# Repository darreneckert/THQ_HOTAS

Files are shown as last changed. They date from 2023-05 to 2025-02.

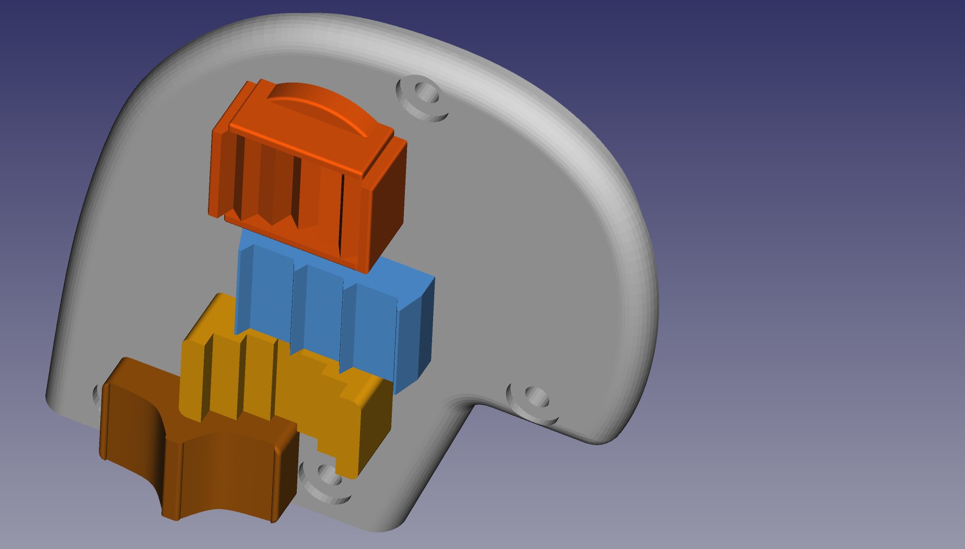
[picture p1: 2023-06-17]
Docs/Proposed Right Throttle Switches and Hat Layout.jpeg

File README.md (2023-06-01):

# THQ_HOTAS
My attempt to add additional controls to the VKB Throttle Quadrant module (THQ).

I plan to use one or two Arduino Pro Micro boards to add a mini joystick, various buttons, hats and switches to the VKB THQ using Marco_596178's Printables throttle bodies (https://www.printables.com/model/405514-vkb-thq-hotas-throttle) and Huzarski's hat switches (https://www.thingiverse.com/thing:3641494)

This is my first time using an Arduino and working on a DIY Hotas.

This repository will contain the Arduino code, schematics and documentation for this project.

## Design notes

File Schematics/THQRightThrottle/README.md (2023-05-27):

# THQRightThrottle

## Description

This is a [LibrePCB](https://librepcb.org) project!

My attempt to add additional controls to VKB THQ using @Marco_596178's Printables throttle grips

## License

This work is licensed under the Creative Commons Attribution-NonCommercial 4.0 International License. To view a copy of this license, visit http://creativecommons.org/licenses/by-nc/4.0/ or send a letter to Creative Commons, PO Box 1866, Mountain View, CA 94042, USA.

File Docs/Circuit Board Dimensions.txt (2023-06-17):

Circuit Board Dimensions (approx.)

Main Board
Length = 43mm
Width  = 33mm

5_Way Hat Board
Length = 23mm
Width  = 20mm

Switches Board
Length = 26mm
Width  = 25mm

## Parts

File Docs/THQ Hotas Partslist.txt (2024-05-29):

THQ Hotas Partslist

THQ Throttle bodies - https://www.printables.com/model/405514-vkb-thq-hotas-throttle

Hat Switches (2x 2-Way, 1x 3-Way, 1x 5-Way) - https://www.thingiverse.com/thing:3641494

12x 0.7mm SPST Micro Tactile Switch - https://www.jaycar.com.au/0-7mm-spst-micro-tactile-switch/p/SP0600

Warthog slew sensor upgrade module, requires 3.3V so need 3.3V/8MHz version of Pro Micro - https://www.aliexpress.com/item/1005002554918990.html?spm=a2g0o.order_list.order_list_main.10.64db1802wJn1Tb

3.3V Arduino Pro Micro - https://www.aliexpress.com/item/1348800135.html?spm=a2g0o.order_list.order_list_main.21.64db1802wJn1Tb

Prototype boards manufactured thru PCBWay/JLCPCB, designed using EasyEDA

Various wires and connectors

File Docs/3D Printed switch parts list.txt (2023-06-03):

2/3/4/5-Way Switches from https://www.thingiverse.com/thing:3641494

2-Way switch parts (Speedbrake)
	2x Alps SKHHAQA010
	1x Cap #A
	1x Stem #A
	1x Body #A
	1x Hat Cap SB
	
2-Way switch parts (Comms)
	2x Alps SKHHAQA010
	1x Cap #A
	1x Stem #A
	1x Body #A
	1x Hat Cap Comms
	
3-Way switch parts (Misc)
	3x Alps SKHHAQA010
	1x Cap #A
	1x Stem #A
	1x Body #A
	1x Bottom #A
	1x Hat Cap Boat

5-Way switch parts
	5x Alps SKHHAQA010
	1x Cap #D
	1x Stem #C
	1x Body #D
	1x Bottom #A
	1x Hat Cap Stadium

Totals
	12x Alps SKHHAQA010
	3x  Cap #A
	1x  Cap #D
	3x  Stem #A
	1x  Stem #C
	3x  Body #A/#B
	1x  Body #D
	2x  Bottom #A
	1x  Hat Cap SB
	1x  Hat Cap Comms
	1x  Hat Cap Boat
	1x  Hat Cap Stadium

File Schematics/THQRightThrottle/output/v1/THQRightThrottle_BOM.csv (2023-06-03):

Quantity | Designators | Value | Device | Package
2 | J_2WAY1, J_2WAY2 |  | Generic Pin Socket 2.54mm 1x03 ⌀1.0mm | Pin Socket 2.54mm 1x03 ⌀1.0mm
1 | J_3WAY |  | Generic Pin Socket 2.54mm 1x04 ⌀1.0mm | Pin Socket 2.54mm 1x04 ⌀1.0mm
5 | J_DOWN, J_LEFT, J_PUSH, J_RIGHT, J_UP |  | Generic Pin Header 2.54mm 1x02 ⌀1.0mm | Pin Header 2.54mm 1x02 ⌀1.0mm
2 | J_HAT, J_HAT2 |  | Generic Pin Header 2.54mm 1x06 ⌀1.0mm | Pin Header 2.54mm 1x06 ⌀1.0mm
2 | J_SWITCHES, J_SWITCHES2 |  | Generic Pin Header 2.54mm 1x08 ⌀1.0mm | Pin Header 2.54mm 1x08 ⌀1.0mm
1 | J_TDC |  | Generic Pin Header 2.54mm 1x05 ⌀1.0mm | Pin Header 2.54mm 1x05 ⌀1.0mm
1 | U_PRO_MICRO |  | Pro Micro - Micro USB | Pro Micro - Micro USB

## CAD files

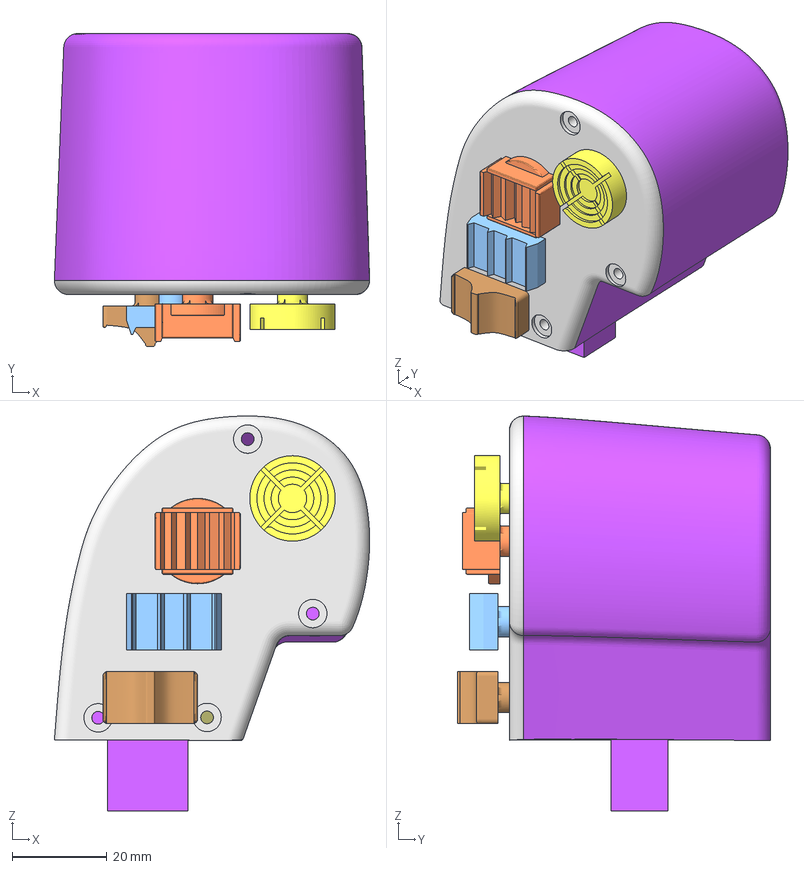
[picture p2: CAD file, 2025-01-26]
Docs/Right THrottle Switches and Hat Layout.FCStd
66.5 x 66.0 x 83.3 mm
Main Board
VKB THQ Hotas v1 - RH Side Panel
Speedbrake
Comms_HAT
Boat
VKB THQ Hotas v1 - RH Body
Stadium_HAT

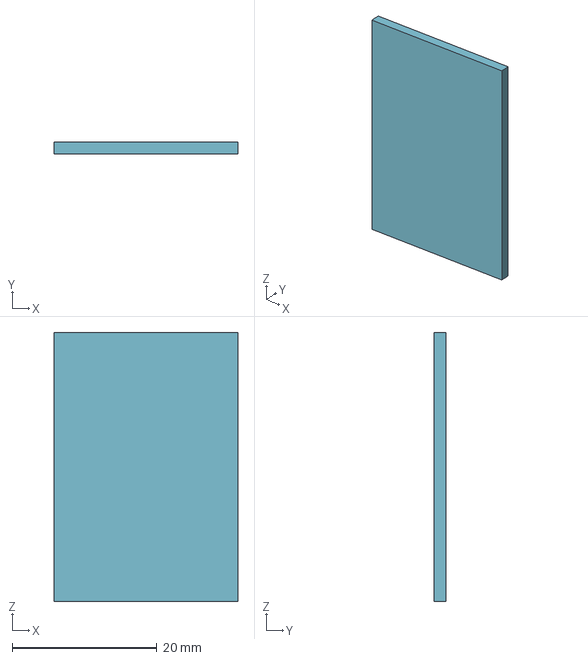
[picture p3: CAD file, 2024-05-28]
Docs/Right Throttle Board.FCStd
25.4 x 1.60 x 37.2 mm

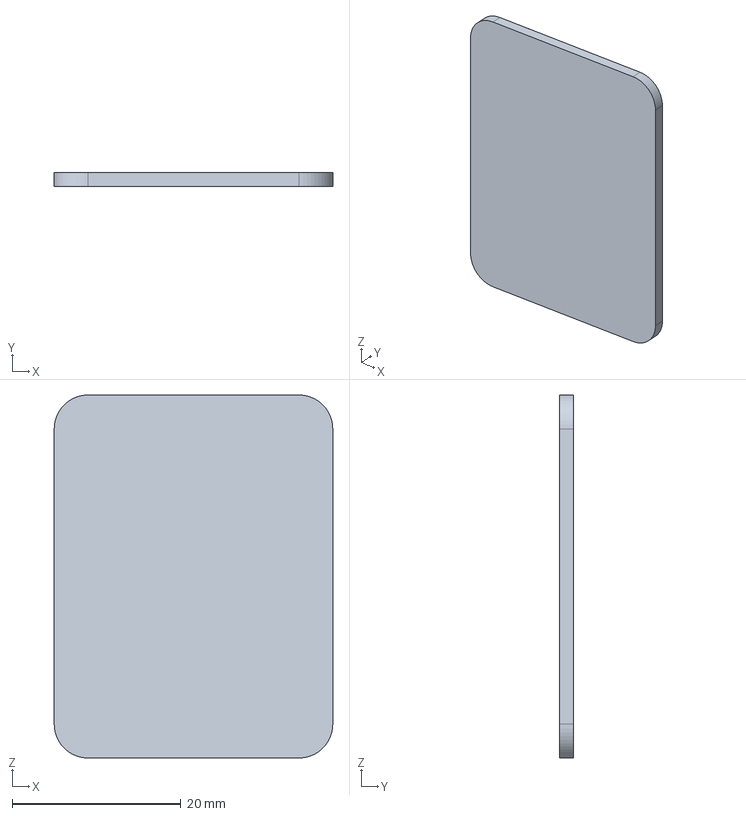
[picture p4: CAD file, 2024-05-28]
Docs/Right Throttle Board rev1.FCStd
33.0 x 1.60 x 43.0 mm

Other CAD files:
Docs/Right Throttle Board.stl

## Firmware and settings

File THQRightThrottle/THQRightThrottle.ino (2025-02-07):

// Program to setup an Arduino Pro Micro to provide additional 
// controls (ministick, hats, buttons and switches) to a
// VKB Throttle Quadrant (THQ) module, making use of the 3D
// printed left and right throttle bodies that have been designed 
// by Marco (@Marco_596178) at Printerbale.com which can be found 
// here - https://www.printables.com/model/405514-vkb-thq-hotas-throttle
//
// This sketch is for the right throttle controls 
//
// Darren Eckert
// 2023-06-12
// Version 0.2

#include <Joystick.h>
#define DEBUGTHQ TRUE


const int HID_ID = 0x26;              // Unique HID Device ID for this arduino
const int uBtns  = 9;                 // Number of buttons on the device
const int hBtns  = 4;                 // Hat switches Up, Right, Down, Left
const int tDelay = 50;                // Time delay for loop() in ms, may need adjusting
int i;                                // Generic counter

// Define digital pin to be used for each  button
int sHat[hBtns] = {0, 1, 4, 2};       // 5-Way Hat U/R/D/L
int sBtn[uBtns] = {3,                 // 5-Way Hat Push switch,   HID button 0
                   6, 7,              // 2-Way Speedbrake switch, HID buttons 1 and 2
                   8, 9,              // 2-Way Comms switch,      HID buttons 3 and 4
                   10, 14, 16,         // 3-Way Misc switch,      HID buttons 5, 6 and 7
                   15};                // TDC Push switch         HID button 8


// Define Analog pins for each axis
const int xTDC_Axis  = A3;            // Analog pin for TDC X-Axis
const int yTDC_Axis  = A2;            // Analog pin for TDC Y-Axis
  

// Default states for axes and buttons
int xTDC = 0;
int yTDC = 0;

bool hVal_Changed = false;
int sBtn_CurrState, hBtn_CurrState;
int sBtn_LastState[uBtns] = {0, 0, 0, 0, 0, 0, 0, 0, 0};
int hBtn_LastState[hBtns] = {0, 0, 0, 0};


// Joystick (HID ID, Type, Buttons, Hats, X-Aix, Y-Axis, Z-Axis, Rx-Axis, Ry-Axis, Rz-Axis, Rudder, Throttle, Accelerator, Brake, Steering);
Joystick_ THQ(HID_ID, JOYSTICK_TYPE_JOYSTICK, uBtns, 1, true, true, false, false, false, false, false, false, false, false, false);
const bool initAutoSendState = true;


void setup() {
  pinMode(xTDC_Axis, INPUT);
  pinMode(yTDC_Axis, INPUT);

  // Initialise digital pin modes and enable pull-up resistors
  for (i=0; i<uBtns-1; i++) {
    pinMode(sBtn[i], INPUT);
    digitalWrite (sBtn[i], HIGH);
  }
  digitalWrite (sBtn[8], LOW);     // TDC Push needs to be reversed else it reads as pushed when not

  for (i=0; i<hBtns; i++) {
    pinMode(sHat[i], INPUT);
    digitalWrite (sHat[i], HIGH);
  }

  THQ.begin(initAutoSendState);

  #ifdef DEBUGTHQ
    Serial.begin(9600);
  #endif
}

void loop() {
  // Read axes and send to HID
  // X-Axis
  xTDC = analogRead(xTDC_Axis);
  //Serial.print("X Axis = ");
  //Serial.print(xTDC);
  xTDC = map(xTDC, 0, 1023, 0, 255);   // scale resolution to reduce jittering, need to test if necessary
  //Serial.print(", mapping to ");
  //Serial.println(xTDC);
  THQ.setXAxis(xTDC);

  // Y-Axis
  yTDC = analogRead(yTDC_Axis);
  //Serial.print(", Y Axis = ");
  //Serial.println(yTDC);
  yTDC = map(yTDC, 0, 1023, 0, 255);  // scale resolution to reduce jittering, need to test if necessary
  //Serial.print(", mapping to ");
  //Serial.println(yTDC);
  THQ.setYAxis(yTDC);

  // Check for change in state of each hat direction and if it has changed send new state to HID
  for (i=0; i<hBtns; i++)  {
    hBtn_CurrState = !digitalRead(sHat[i]);
   // Serial.print("Current state of sHat[");
   // Serial.print(i);
   // Serial.print("] = ");
   // Serial.println(hBtn_CurrState);
    if (hBtn_CurrState != hBtn_LastState[i]) {
      hVal_Changed = true;
      //Serial.println("State changed from last check");
      hBtn_LastState[i] = hBtn_CurrState;
    }
  }

  // Something has changed since last check
  if (hVal_Changed) {
    // No switch is currently active, release hat switch
    if ((hBtn_LastState[0] == 0) && 
        (hBtn_LastState[1] == 0) &&
        (hBtn_LastState[2] == 0) &&
        (hBtn_LastState[3] == 0)) {
          THQ.setHatSwitch(0, -1);
        }

    // Up Switch pressed
    if (hBtn_LastState[0] == 1) {
      THQ.setHatSwitch(0, 0);
      #ifdef DEBUGTHQ 
        //Serial.println("POV Up pressed!"); 
      #endif
    }
    // Right Switch pressed
    if (hBtn_LastState[1] == 1) {
      THQ.setHatSwitch(0, 90);
    }
    // Down Switch pressed
    if (hBtn_LastState[2] == 1) {
      THQ.setHatSwitch(0, 180);
    }
    // Left Switch pressed
    if (hBtn_LastState[3] == 1) {
      THQ.setHatSwitch(0, 270);
    }

  }

  // Check for change in state of each button and if it has changed send new state to HID
  for (i=0; i<uBtns-1; i++) {
    sBtn_CurrState = !digitalRead(sBtn[i]);
    if (sBtn_CurrState != sBtn_LastState[i]) {
      THQ.setButton(i, sBtn_CurrState);
      sBtn_LastState[i] = sBtn_CurrState;  

    }
  }
  sBtn_CurrState = digitalRead(sBtn[uBtns-1]);
    if (sBtn_CurrState != sBtn_LastState[uBtns-1]) {
      THQ.setButton(uBtns-1, sBtn_CurrState);
      sBtn_LastState[uBtns-1] = sBtn_CurrState;  

    }

  delay (tDelay);
}

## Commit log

2023-05-28 Added planned switch parts list to Docs and updated schematics
2023-05-30 Added hat and extra buttons/switches to Arduino code and schematics
2023-06-01 Updated Schematics
2023-06-03 Added some documents and more schematic updates
2023-06-03 Corrected a couple of wrong components on right throttle and initial commit for left throttle
    [THQRightThrottle_BOM.csv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]
2023-06-03 Corrected file location for left throttle arduino code
    [THQLeftThrottle.ino]
2023-06-17 Schematic changes
2023-06-17 Added custome Arduino IDE board profiles to Docs
2023-06-17 Moved schematics from librePCB to EasyEDA
    [THQRightThrottle_BOM.csv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]
2023-06-17 Initial layout of switches in FreeCAD
    [Right THrottle Switches and Hat Layout.FCStd]
2024-05-28 Initial schematic for I2C version for use with Warthog slew module
    [Right THrottle Switches and Hat Layout.FCStd, Right Throttle Board rev1.FCStd, Right Throttle Board.FCStd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]
2024-05-28 Update copper poour area in PCB layout
2024-05-29 Minor changes to PCB layout prior to getting prototype boards made
2024-05-30 Starting on arduino code for I2C version
2025-01-26 Reorganising files a bit
    [Right THrottle Switches and Hat Layout.FCStd]
2025-02-02 Minor fixes to analog slew control code
    [THQRightThrottle.ino]
2025-02-07 Minor changes to I2C PCB
2025-02-17 More changes to I2C PCB
2025-11-07 Fix some issues with I2C schematic/pcb
2026-01-16 Fixing issues with I2C code, still more work to be done.
    [THQRightThrottleI2C.ino]
2026-01-19 Some more I2C code updates.
